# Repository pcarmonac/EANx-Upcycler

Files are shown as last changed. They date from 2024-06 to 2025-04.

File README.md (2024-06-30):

# EANx-Upcycler

Enhanced feature version on Platform IO of this project https://github.com/lbehrler/EANx-Analyzer-Arduino

# EANx-Analyzer-Arduino / ESP32 

> **Note:** If you have an issue with this project, please review your hardware docuemntation first.  If you are still having an issue or have a software specific issue, please open an issue [here](https://github.com/lbehrler/EANx-Upcycler/issues).

EANx Analysis with output to an OLED color display.
The code can be customized to match a wide variety of hardware.  The current version in the main branch is setup to use an ESP32-Pico-D4, a Seeeduino Xiao, or an Arduino Nano with an SPI interface OLED screen 240 x 240.

In its simplest form the EANx Analyzer reads an analog input from an ADS1115, converts it to voltage, grabs a running average of ADC values and and prints the result to the display and debug to Serial Monitor.

The EANx Analyzer project is meant to be a DIY O2 Analyzer.  

## Disclaimers

**Using or monitoring oxygen levels above atmospheric composition (20.9%) can be hazardous. While oxygen is not combustible or explosive, its presence accelerates and promotes combustion. High levels of oxygen will make most materials combustible including metals. Do not use oxygen levels above 20.9% in the presence of any flame or ignition source.**

**Use at your own risk.  Inaccurate gas analysis can lead to serious personal injury or death.**  

If you are using the device and software for critical purposes, please seek proper training and know the limits of devices of this type. By using this analyzer to analyze breathing gas, you assume all risks for the use of analyzed gas and the risk from any inferences made from the output of the device, both above and below the water.

## Acknowledgements
Some of this code is adapted from other EANx project scripts: 
  - https://github.com/ppppaoppp/DIY-Nitrox-Analyzer-04_12_2019.git
  - https://github.com/ejlabs/arduino-nitrox-analyzer.git

## Basic Operations 
Unit is rechargeable with any 5-20v USB-C negotiating charger (i.e. phone charger).  The unit has a battery meter in the upper right of the screen for the 16340 battery status, and in the upper left for the sensor unit.   If the sensor unit is yellow or red, please replace the O2 sensor, if the battery monitor is yellow or red please fully charge the unit before use. 

### Firmware and Package Upates
The recommended method for firmware updates or to reflash your device is to use the browser based updater here:  ([Firmware Update Page](https://lbehrler.github.io/EANxUpcycler.github.io/)).

Alternately updates can be made using Expressif's ESP Flash Download Tool or an online Serial Connection tool (https://serial.huhn.me/) to update the firmware on your device.  Do so with caution the firmware portion starts at 0x10000 memory position. 

## Project Files

The project folder contains several files and one folder:

+ `LICENSE` - The license file for this project
+ `readme.md` - This file.
+ `EANx_Analyzer_XXXXXXX.ino` - the basic application.
+ `pin_config.h` - Header file for various ESP32 / Arduino pinout settings. 
+ `OTA.h` - Simple OTA upate header (optional utility).
+ `bat_stat.h` - Simple Battery status script for ESP32 based boards.

## Configuration
Depending on your hardware configuration and components used you will have to set your pin definitions in the header files. 

If you are using a basic ST3%XX or ST13XX series display you can use [U8g2](https://github.com/olikraus/u8g2) or the Adafruit librarires. For more advance display features and better efficiency the [Bodmer TFT eSPI library](https://github.com/Bodmer/TFT_eSPI) can be configured allowing for greater options. If you are using the EANx Analyzer OLED TFT eSPI.ino then the TFT eSPI library is required. 

## Revision History
+ 11/29/2022 - initial release
+ 12/30/2022 - prototype release
+ 01/03/2023 - custom PCB prototype release
+ 07/20/2023 - custom PCB option ESP32 release

## Schematics 

*Seeeduino Xiao version with SPI OLED:*


## Prototype

The current prototype unit is built using:
+ LilyGo-T-OI-PLUS [ESP32 C3 with 16340 Battery holder](https://github.com/Xinyuan-LilyGO/LilyGo-T-OI-PLUS)
+ Generic ADS1115 
+ SPI Organic light-emitting diode (OLED) ST7789
+ O2 Sensor
+ 16340 Battery
+ Custom PCB fit to project case
+ Project case

*Prototype 4*

Custom PCB version

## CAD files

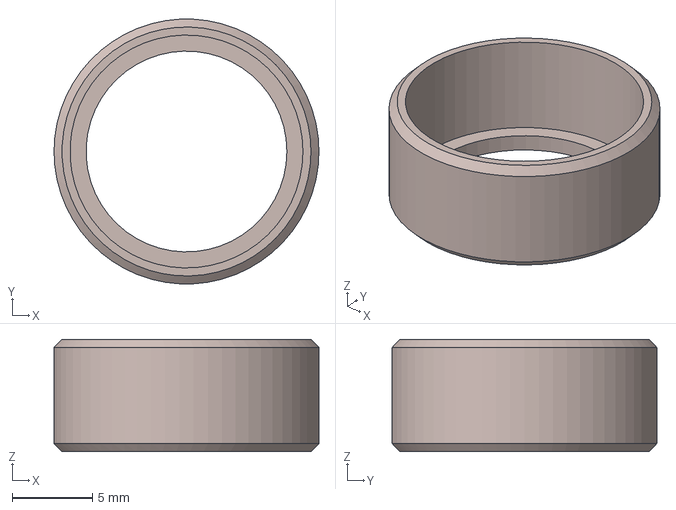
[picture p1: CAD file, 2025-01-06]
STL/EAN Switch Shroud V1.step
16.5 x 16.5 x 7.00 mm

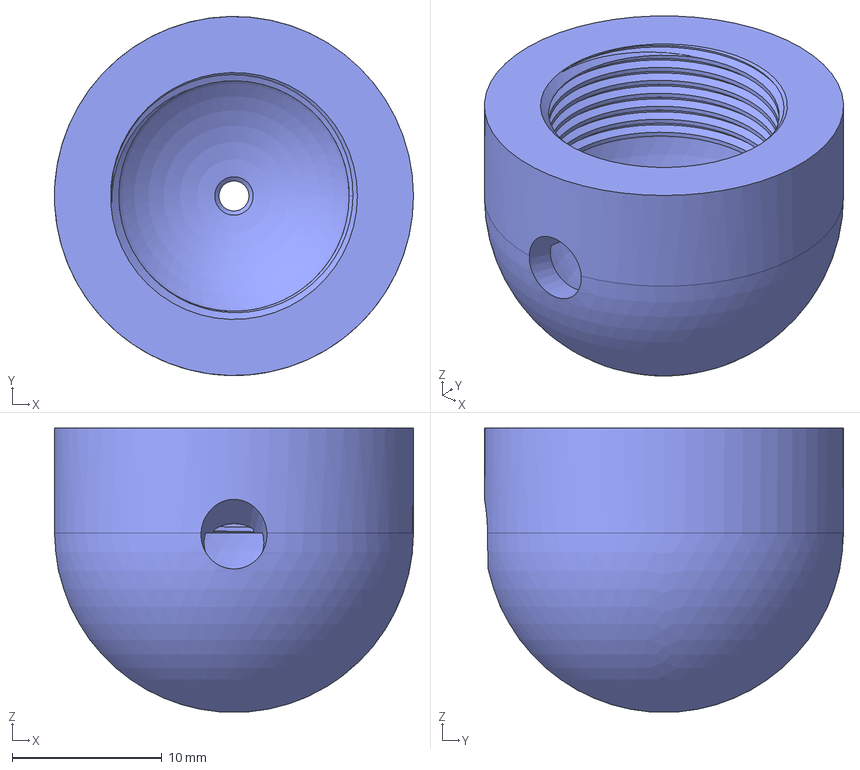
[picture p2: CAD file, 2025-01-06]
STL/EAN Cap V2.step
24.0 x 24.0 x 19.0 mm

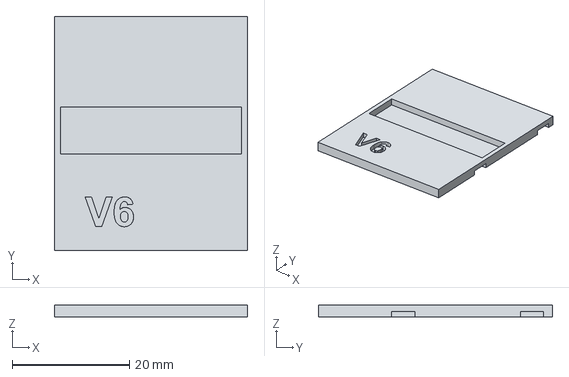
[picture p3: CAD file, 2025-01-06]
STL/EAN PCB Spacer V6.step
33.0 x 40.0 x 2.10 mm

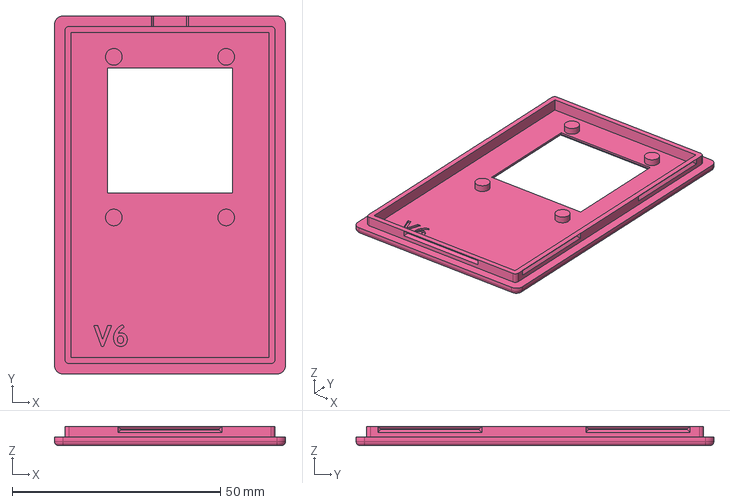
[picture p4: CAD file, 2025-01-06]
STL/EAN Lid V6.step
55.5 x 86.0 x 4.60 mm

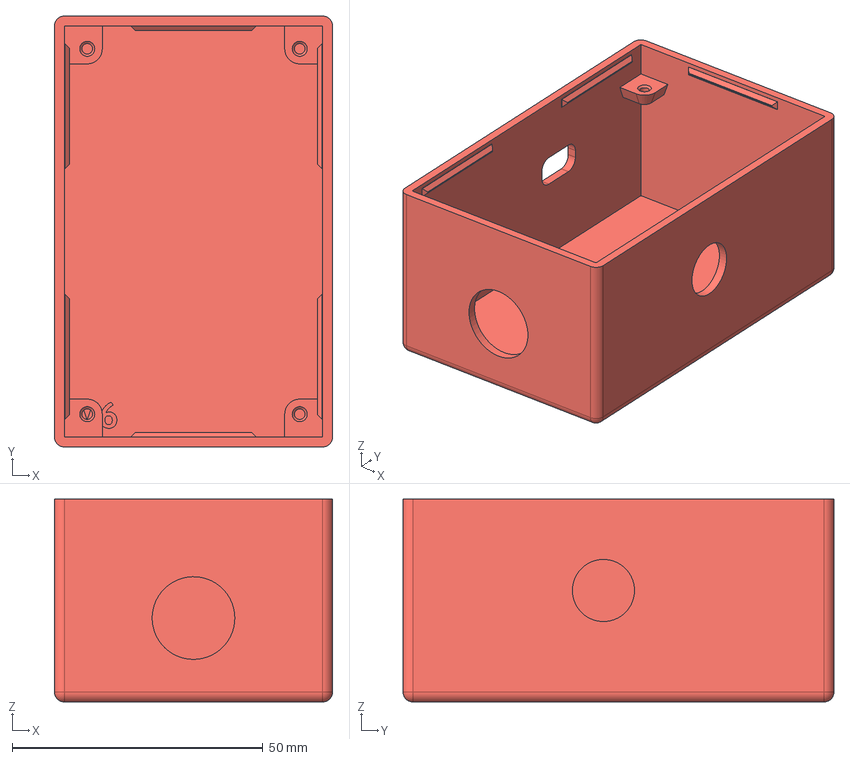
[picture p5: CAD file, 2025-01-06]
STL/EAN Box V6.step
55.5 x 86.0 x 40.5 mm

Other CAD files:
STL/EAN Box V6.stl
STL/EAN Lid V6.stl

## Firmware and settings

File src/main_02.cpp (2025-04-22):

/*****************************************************************************

  EANx Analysis with output to an OLED color display

  Reads an analog input from an ADC, converts it to mV, and creates a running average
  of ADC values and and prints the result to the display and debug to Serial Monitor.

  Based on prior EANx scripts:
  https://github.com/ppppaoppp/DIY-Nitrox-Analyzer-04_12_2019.gitf
  https://github.com/ejlabs/arduino-nitrox-analyzer.git

  Brian Ehrler 2022-2023
*****************************************************************************/

// Libraries
#include <Arduino.h>
// #include <Wire.h>
#include <RunningAverage.h>
#include <SPI.h>
#include <Adafruit_GFX.h> // Core graphics library
#include <TFT_eSPI.h>
#include <Adafruit_ADS1X15.h>
// #include <stdint.h>
#include "pin_config.h"
#include "version.h"
#include <EEPROM.h>

// Debugging
#define DEBUG 1

#if DEBUG == 1
#define debug(x) Serial.print(x)
#define debugln(x) Serial.println(x)
#else
#define debug(x)
#define debugln(x)
#endif

// Display Definitions
#define TFT_WIDTH 240  // OLED display width, in pixels
#define TFT_HEIGHT 240 // OLED display height, in pixels
#define ResFact 2      // 1 = 128x128   2 = 240x240 
#define ROUNDISP 0     // 1= yes 0= no

// User Interface Settings -----------------------------------------------------------------
#define GUI 0       // 1= on 0= off
#define nerds 1     // 1= on 0= off   GUI of 1 will override this setting
#define metric 0    // 1= on 0= off   Available since 1866 in the US
#define statinfo 1  // 2= bottom 1= top, 0= off [GUI requires off]
#define MOD 1       // 1= on 0= off
#define RODA 0      // 1= on 0= off


// Init tft and sprites
TFT_eSPI tft = TFT_eSPI();

TFT_eSprite gauge = TFT_eSprite(&tft);
TFT_eSprite background = TFT_eSprite(&tft);
TFT_eSprite needle = TFT_eSprite(&tft);
  
// Init ADS
Adafruit_ADS1115 ads; // Define ADC - 16-bit version

// Running Average definitions
#define RA_SIZE 20          // Define running average pool size
RunningAverage RA(RA_SIZE); // Initialize Running Average

// Global Variables
int LCDROT = 0; // 0 = default, 1 = CW 90
float tbFactor = 0;
float spFactor = 0;
float prevaveSensorValue = 0;
float aveSensorValue = 0;
float mVolts = 0;
float batVolts = 0;
int eepromAddr = 0;
float prevO2 = 0;
float currentO2 = 0;
float calFactor = 1;
float calErrChk = 1;
int mod14fsw = 0;
int mod14msw = 0;
int mod16fsw = 0;
int mod16msw = 0;
float modppo = 1.4;
float mod16ppo = 1.6;
float multiplier = 0;
int msgid = 0;

#if GUI == 1
// Define display colors
#define backColor TFT_BLACK
#define gaugeColor 0x055D
#define dataColor 0x0311
#define needleColor 0xF811
#define color1 TFT_WHITE
#define color2 0x8410
#define color3 TFT_ORANGE
#define color4 0x15B3
#define color5 0x00A3

#define DEG2RAD 0.0174532925

// Gauge variables
float o2Angle = 0;  // range 0-100
float modAngle = 0; // range 10-250

int centerX = 120; // centerX and sy
int centerY = -75;
int centerX2 = 120;
int centerY2 = 330;
int r = 180; // outer radius tickmarks ... offset r-5 for line end, r-15 for text

int uprAngle = 0;
int lwrAngle = 0;
int o2OffAgl = 90;
int modOffAgl = 270;

String o2[10] = {"0", "10", "20", "30", "40", "50", "60", "70", "80", "90"};
String mod[10] = {"0", "30", "60", "90", "120", "150", "180", "210", "240", "270"};
int o2Start[10];
int o2StartP[60];
int modStart[10];
int modStartP[60];

float x[360]; // pixel points O2 gauge
float y[360];
float px[360]; // line end points O2 gauge
float py[360];
float lx[360]; // text of O2 gauges
float ly[360];

float x2[360]; // outer points of MOD gauges
float y2[360];
float px2[360]; // ineer point of MOD gauges
float py2[360];
float lx2[360]; // text of MOD gauges
float ly2[360];

#endif

const int buttonPin = BUTTON_PIN; // push button

// Functions
float batStat();

/*void gotoSleep() 
{
  Serial.println("going to sleep in 3 sec....");   
  delay(3000); 
  esp_deep_sleep_enable_gpio_wakeup(1ULL << buttonPin,ESP_GPIO_WAKEUP_GPIO_HIGH);  
  digitalWrite(TFT_BL, LOW); // turns off backlight
  delay(120); // Delay for shutdown time before another command can be sent
  Serial.println("going to sleep now"); 
  delay(1000);
  tft.writecommand(0x10); // Sleep
  delay(5); // Delay for shutdown time before another command can be sent
  esp_deep_sleep_start();
  //esp_light_sleep_start();
}*/

void SenseFault()
{
  debugln("Low mV reading from Sensor");
  tft.fillScreen(TFT_YELLOW);
  tft.setTextColor(TFT_RED);
  tft.setTextSize(1 * ResFact);
  tft.drawCentreString("Error", TFT_WIDTH * 0.5, TFT_HEIGHT * 0.1, 4);
  tft.drawCentreString("Sensor mV", TFT_WIDTH * 0.5, TFT_HEIGHT * 0.4, 4);
  tft.drawCentreString("LOW", TFT_WIDTH * 0.5, TFT_HEIGHT * 0.7, 4);
  tft.setTextSize(1);
  tft.drawCentreString(String(mVolts), TFT_WIDTH * .5, TFT_HEIGHT * 0.8, 4);
  delay(30000);
}

void BattFault()
{
  debugln("Low V reading from Battery");
  tft.fillScreen(TFT_YELLOW);
  tft.setTextColor(TFT_RED);
  tft.setTextSize(1 * ResFact);
  tft.drawCentreString("Error", TFT_WIDTH * 0.5, TFT_HEIGHT * 0.1, 4);
  tft.drawCentreString("Battery", TFT_WIDTH * 0.5, TFT_HEIGHT * 0.4, 4);
  tft.drawCentreString("Low", TFT_WIDTH * 0.5, TFT_HEIGHT * 0.7, 4);
  tft.setTextSize(1);
  tft.drawCentreString(String(batVolts), TFT_WIDTH * .5, TFT_HEIGHT * 0.8, 4);
  delay(30000);
}

float initADC()
{
  // init ADC and Set gain

  // The ADC input range (or gain) can be changed via the following
  //                                                                ADS1015  ADS1115
  //                                                                -------  -------
  // ads.setGain(GAIN_TWOTHIRDS);  // 2/3x gain +/- 6.144V  1 bit = 3mV      0.1875mV (default)
  // ads.setGain(GAIN_ONE);        // 1x gain   +/- 4.096V  1 bit = 2mV      0.125mV
  ads.setGain(GAIN_TWO); // 2x gain   +/- 2.048V  1 bit = 1mV      0.0625mV
  // ads.setGain(GAIN_FOUR);       // 4x gain   +/- 1.024V  1 bit = 0.5mV    0.03125mV
  // ads.setGain(GAIN_EIGHT);      // 8x gain   +/- 0.512V  1 bit = 0.25mV   0.015625mV
  // ads.setGain(GAIN_SIXTEEN);    // 16x gain  +/- 0.256V  1 bit = 0.125mV  0.0078125mV

  /* Be sure to update this value based on the IC and the gain settings! */
  // float   multiplier = 3.0F;    /* ADS1015 @ +/- 6.144V gain (12-bit results) */
  float multiplier = 0.0625; /* ADS1115  @ +/- 6.144V gain (16-bit results) */

  // Check that the ADC is operational
  if (!ads.begin())
  {
    debugln("Failed to initialize ADC.");
    tft.fillScreen(TFT_YELLOW);
    tft.setTextColor(TFT_RED);
    tft.setTextSize(1 * ResFact);
    tft.drawCentreString("Error", TFT_WIDTH * 0.5, TFT_HEIGHT * 0.1, 4);
    tft.drawCentreString("ADC", TFT_WIDTH * 0.5, TFT_HEIGHT * 0.4, 4);
    tft.drawCentreString("Fail", TFT_WIDTH * 0.5, TFT_HEIGHT * 0.7, 4);
    delay(30000);
    while (1);
  }
  return (multiplier);
}

void o2calibration()
{
  int cal = 1;
  do
  {
    // display "Calibrating"
    tft.fillScreen(TFT_BLACK);
    tft.setTextColor(TFT_WHITE);
    tft.setTextSize(1 * ResFact);
    tft.drawCentreString("+++++++++++++", TFT_WIDTH * 0.5, TFT_HEIGHT * 0.1, 2);
    tft.drawCentreString("Calibrating", TFT_WIDTH * 0.5, TFT_HEIGHT * 0.3, 2);
    tft.drawCentreString("O2 Sensor", TFT_WIDTH * 0.5, TFT_HEIGHT * 0.6, 2);
    tft.drawCentreString("+++++++++++++", TFT_WIDTH * 0.5, TFT_HEIGHT * 0.8, 2);
    debugln("Calibration Screen Text");

    // get running average value from ADC input Pin
    RA.clear(); 
    for (int x = 0; x <= (RA_SIZE * 3); x++)
    {
      int sensorValue = 0;
      sensorValue = abs(ads.readADC_Differential_0_1());
      RA.addValue(sensorValue);
      delay(12); // was 8
    }
    debug("Average calibration read ");
    debugln(RA.getAverage()); // average cal factor serial print for debugging
    calFactor = RA.getAverage();
    delay(1000); // Slow the loop for checksum

    // Checksum on calibrate ... is the sensor still reseting from earlier read
    RA.clear();
    for (int x = 0; x <= (RA_SIZE * 3); x++)
    {
      int sensorValue = 0;
      sensorValue = abs(ads.readADC_Differential_0_1());
      RA.addValue(sensorValue);
      delay(36); // was 24
    }

    tft.fillScreen(TFT_BLACK);

    calErrChk = RA.getAverage();
    debug("calibration raw values Calfactor=");
    debug(calFactor); // average cal factor
    debug(" CalErrChk=");
    debugln(calErrChk); // average cal err factor serial print for debugging

    debugln(abs((calFactor / calErrChk) - 1) * 100);

    // checking against a 0.5% error
    if (abs((calFactor / calErrChk) - 1) * 100 > 0.5)
    {
      debugln("Calibration Checksum out of spec");
      tft.fillScreen(TFT_ORANGE);
      tft.setTextColor(TFT_BLACK);
      tft.setTextSize(1 * ResFact);
      tft.drawCentreString("+++++++++++++", TFT_WIDTH * 0.5, TFT_HEIGHT * 0.1, 2);
      tft.drawCentreString("Refining", TFT_WIDTH * 0.5, TFT_HEIGHT * 0.25, 2);
      tft.drawCentreString("Calibration", TFT_WIDTH * 0.5, TFT_HEIGHT * 0.45, 2);
      tft.drawCentreString("Standby", TFT_WIDTH * 0.5, TFT_HEIGHT * 0.65, 2);
      tft.drawCentreString("+++++++++++++", TFT_WIDTH * 0.5, TFT_HEIGHT * 0.80, 2);
      tft.drawCentreString(String(abs((calFactor / calErrChk) - 1) * 100), TFT_WIDTH * 0.5, TFT_HEIGHT * 0.80, 1);
      delay(2000);
      cal = 1;
    }
    else
    {
      cal = 0;
    }
  } while (cal);

  calFactor = (1 / RA.getAverage() * 20.900); // Auto Calibrate to 20.9%
}

void BatGauge(int locX, int locY, float batV)
{

#if GUI == 1
  // Add to gauge sprite
  gauge.drawRect(locX, locY, 25, 12, TFT_WHITE);
  gauge.drawRect((locX + 25), (locY + 4), 3, 4, TFT_WHITE);
  gauge.fillRect((locX + 1), (locY + 1), 23, 10, TFT_BLACK);

  // Fill with the color that matches the charge state
  if (batV >= 3.4 and batV < 3.6)
  {
    gauge.fillRect((locX + 1), (locY + 1), 15, 10, TFT_YELLOW);
  }
  if (batV < 3.4)
  {
    gauge.fillRect((locX + 1), (locY + 1), 10, 10, TFT_RED);
  }
  if (batV >= 3.6)
  {
    gauge.fillRect((locX + 1), (locY + 1), 23, 10, TFT_GREEN);
  }
#else
  // Draw the outline and clear the box
  tft.drawRect(locX, locY, 25, 12, TFT_WHITE);
  tft.drawRect((locX + 25), (locY + 4), 3, 4, TFT_WHITE);
  tft.fillRect((locX + 1), (locY + 1), 23, 10, TFT_BLACK);

  // Fill with the color that matches the charge state
  if (batV > 3.4 and batV < 3.6)
  {
    tft.fillRect((locX + 1), (locY + 1), 15, 10, TFT_YELLOW);
  }
  if (batV < 3.4)
  {
    tft.fillRect((locX + 1), (locY + 1), 10, 10, TFT_RED);
  }
  if (batV > 3.6)
  {
    tft.fillRect((locX + 1), (locY + 1), 23, 10, TFT_GREEN);
  }
#endif
  if (batV < 3.2) { BattFault(); }

}

void SenseGauge(int locX, int locY, float senV)
{

#if GUI == 1
  // Draw the outline and clear the box
  gauge.drawRect(locX, locY, 25, 12, TFT_WHITE);
  gauge.drawRect((locX + 5), (locY - 3), 4, 3, TFT_WHITE);
  gauge.drawRect((locX + 16), (locY - 3), 4, 3, TFT_WHITE);
  gauge.fillRect((locX + 1), (locY + 1), 23, 10, TFT_BLACK);

  // Fill with the color that matches the charge state
  if (senV >= 9.0)
  {
    gauge.fillRect((locX + 1), (locY + 1), 23, 10, TFT_BLUE);
  }
  if (senV >= 8 and senV < 9.0 )
  {
    gauge.fillRect((locX + 1), (locY + 1), 23, 10, TFT_GREEN);
  }
  if (senV > 7.5 and senV < 8.0)
  {
    gauge.fillRect((locX + 1), (locY + 1), 23, 10, TFT_YELLOW);
  }
  if (senV <= 7.5)
  {
    gauge.fillRect((locX + 1), (locY + 1), 23, 10, TFT_RED);
  }

#else
  // Draw the outline and clear the box
  tft.drawRect(locX, locY, 25, 12, TFT_WHITE);
  tft.drawRect((locX + 5), (locY - 3), 4, 3, TFT_WHITE);
  tft.drawRect((locX + 16), (locY - 3), 4, 3, TFT_WHITE);
  tft.fillRect((locX + 1), (locY + 1), 23, 10, TFT_BLACK);

  // Fill with the color that matches the charge state
  if (senV > 7.5 and senV < 8.0)
  {
    tft.fillRect((locX + 1), (locY + 1), 23, 10, TFT_YELLOW);
  }
  if (senV >= 8 and senV < 9.0 )
  {
    tft.fillRect((locX + 1), (locY + 1), 23, 10, TFT_GREEN);
  }
  if (senV <= 7.5)
  {
    tft.fillRect((locX + 1), (locY + 1), 23, 10, TFT_RED);
  }
  if (senV >= 9.0)
  {
    tft.fillRect((locX + 1), (locY + 1), 23, 10, TFT_BLUE);
  }
#endif

if (senV < 7.1) { SenseFault(); }

}

void testfillcircles(uint8_t radius, uint16_t color)
{
  for (int16_t x = radius; x < tft.width(); x += radius * 2)
  {
    for (int16_t y = radius; y < tft.height(); y += radius * 2)
    {
      tft.fillCircle(x, y, radius, color);
    }
  }
}

void testdrawcircles(uint8_t radius, uint16_t color)
{
  for (int16_t x = 0; x < tft.width() + radius; x += radius * 2)
  {
    for (int16_t y = 0; y < tft.height() + radius; y += radius * 2)
    {
      tft.drawCircle(x, y, radius, color);
    }
  }
}

void safetyrule()
{
  tft.fillScreen(TFT_BLACK);
  tft.setTextColor(TFT_YELLOW);
  tft.setTextSize(1 * ResFact);
  randomSeed(millis());
  int randNumber = random(5);
  if (randNumber == 0)
  {
    tft.drawCentreString("Seek proper", TFT_WIDTH * 0.5, TFT_HEIGHT * 0.1, 2);
    tft.drawCentreString("training", TFT_WIDTH * 0.5, TFT_HEIGHT * 0.25, 2);
  }
  else if (randNumber == 1)
  {
    tft.drawCentreString("Maintain a", TFT_WIDTH * 0.5, TFT_HEIGHT * 0.1, 2);
    tft.drawCentreString("continious", TFT_WIDTH * 0.5, TFT_HEIGHT * 0.25, 2);
    tft.drawCentreString("guideline to", TFT_WIDTH * 0.5, TFT_HEIGHT * 0.4, 2);
    tft.drawCentreString("the surface", TFT_WIDTH * 0.5, TFT_HEIGHT * 0.55, 2);
  }
  else if (randNumber == 2)
  {
    tft.drawCentreString("Stay within", TFT_WIDTH * 0.5, TFT_HEIGHT * 0.1, 2);
    tft.drawCentreString("your depth", TFT_WIDTH * 0.5, TFT_HEIGHT * 0.25, 2);
    tft.drawCentreString("limitations", TFT_WIDTH * 0.5, TFT_HEIGHT * 0.4, 2);
  }
  else if (randNumber == 3)
  {
    tft.drawCentreString("Proper gas", TFT_WIDTH * 0.5, TFT_HEIGHT * 0.1, 2);
    tft.drawCentreString("management", TFT_WIDTH * 0.5, TFT_HEIGHT * 0.25, 2);
  }
  else
  {
    tft.drawCentreString("Use appropriate", TFT_WIDTH * 0.5, TFT_HEIGHT * 0.1, 2);
    tft.drawCentreString("properly maintaned", TFT_WIDTH * 0.5, TFT_HEIGHT * 0.25, 2);
    tft.drawCentreString("equipment", TFT_WIDTH * 0.5, TFT_HEIGHT * 0.4, 2);
  }
  delay(2000);
  tft.fillScreen(TFT_BLACK);
}

void displayUtilData()
{

  BatGauge((TFT_WIDTH * 0.8), (TFT_HEIGHT * (tbFactor + 0.02)), (batVolts));
  SenseGauge((TFT_WIDTH * 0.1), (TFT_HEIGHT * (tbFactor + 0.02)), (mVolts));

  // Stats for nerds text
  #if (nerds == 1 and GUI == 0)

    tft.setTextSize(1);
    if (mVolts > 7.5 and mVolts <= 9.0) { tft.setTextColor(TFT_YELLOW, TFT_BLACK); }
    if (mVolts <= 7.5) { tft.setTextColor(TFT_RED, TFT_BLACK); }
    if (mVolts > 9.0) { tft.setTextColor(TFT_SKYBLUE, TFT_BLACK); }
    if (mVolts < 7.1) { SenseFault(); }
    String mv = String(mVolts, 1);

    tft.drawCentreString(String(mv + " mV "), TFT_WIDTH * 0.18, TFT_HEIGHT * 0.1, 2);

    if (batVolts > 3.4 and batVolts < 3.6) { tft.setTextColor(TFT_YELLOW, TFT_BLACK); }
    if (batVolts < 3.4) { tft.setTextColor(TFT_RED, TFT_BLACK); }
    if (batVolts > 3.6) { tft.setTextColor(TFT_GREEN, TFT_BLACK); }

    String bv = String(batVolts, 1);
    if (batVolts < 3.2) { BattFault(); }

    tft.drawCentreString(String(bv + " V  "), TFT_WIDTH * 0.88, TFT_HEIGHT * 0.1, 2);

    //tft.drawString(String(millis() / 1000), TFT_WIDTH * 0.05, TFT_HEIGHT * 0, 2);
    tft.setTextSize(1);
    tft.setTextColor(TFT_LIGHTGREY, TFT_BLACK);
    tft.drawCentreString(String(VERSION), TFT_WIDTH * 0.5, TFT_HEIGHT * 0.93, 2);
  #endif
}

#if GUI == 0
void textBaseLayout()
{
  // Draw Layout -- Adjust this layouts to suit you LCD

  tft.setTextColor(TFT_MAGENTA, TFT_BLACK);
  tft.setTextSize(1 * ResFact);
  tft.drawCentreString("O %", TFT_WIDTH * 0.5, TFT_HEIGHT * 0, 4);
  tft.setTextSize(1);
  tft.drawCentreString("2", TFT_WIDTH * 0.5, TFT_HEIGHT * 0.1, 4);
  tft.setTextSize(1 * ResFact);
  tft.setTextColor(TFT_ORANGE, TFT_BLACK);
  if (MOD == 1)
  {
    tft.drawCentreString("@1.4  MOD  @1.6", TFT_WIDTH * 0.5, TFT_HEIGHT * 0.62, 2);
  }
  
  debugln("Base layout");
}

void displayTextData()
{
  // Generate Text layout
  if (prevO2 != currentO2)
  {
    if (currentO2 > 19.5 and currentO2 < 22)
    {
      tft.setTextColor(TFT_CYAN, TFT_BLACK);
    }
    if (currentO2 <= 19.5)
    {
      tft.setTextColor(TFT_YELLOW, TFT_BLACK);
    }
    if (currentO2 <= 17)
    {
      tft.setTextColor(TFT_RED, TFT_BLACK);
    }
    if (currentO2 >= 22)
    {
      tft.setTextColor(TFT_GREEN, TFT_BLACK);
    }

    // Draw Text Layout -- Adjust these layouts to suit you LCD
    tft.setTextSize(1 * ResFact);
    String o2 = String(currentO2, 1);
    float h = 0.22;
    if (MOD == 0)
    {
      h = 0.35;
    }

    tft.drawCentreString(o2, TFT_WIDTH * 0.5, TFT_HEIGHT * h, 7);
    debugln("Write O2 string");
  
    tft.setTextSize(1 * ResFact);
    if (MOD == 1)
    {
      if (metric == 1)
      {
        String mod14m = String(mod14msw);
        tft.setTextColor(TFT_GREENYELLOW, TFT_BLACK);
        tft.drawString(String(mod14m + "-m  "), TFT_WIDTH * 0.05, TFT_HEIGHT * 0.75, 2);
        tft.setTextColor(TFT_GOLD, TFT_BLACK);
        String mod16m = String(mod16msw);
        tft.drawString(String(mod16m + "-m  "), TFT_WIDTH * 0.7, TFT_HEIGHT * 0.75, 2);
      }
      else
      {
        tft.setTextColor(TFT_GREENYELLOW, TFT_BLACK);
        String mod14f = String(mod14fsw);
        tft.drawString(String(mod14f + "-FT  "), TFT_WIDTH * 0, TFT_HEIGHT * 0.75, 2);
        tft.setTextColor(TFT_GOLD, TFT_BLACK);
        String mod16f = String(mod16fsw);
        tft.drawString(String(mod16f + "-FT  "), TFT_WIDTH * 0.6, TFT_HEIGHT * 0.75, 2);
      }
    }
  }
}
#endif

#if GUI == 1
void gaugeBaseLayout()
{
  // Draw Layout -- Adjust this layouts to suit you LCD
  gauge.createSprite(TFT_WIDTH, 240);
  gauge.setSwapBytes(true);
  gauge.setTextDatum(4);
  gauge.setTextColor(TFT_WHITE, backColor);
  needle.createSprite(TFT_WIDTH, 240);
  needle.setSwapBytes(true);
  background.createSprite(TFT_WIDTH, 240);
  background.setSwapBytes(true);
  background.fillSprite(TFT_BLACK);

  int b = 0;
  int b2 = 0;
  int c = 0;
  int c2 = 0;

  // Set up polar coordinates for gauge
  for (int i = 0; i < 360; i++)
  {
    x[i] = ((r)*cos(DEG2RAD * i)) + centerX; // Shading
    y[i] = ((r)*sin(DEG2RAD * i)) + centerY;
    px[i] = ((r - 14) * cos(DEG2RAD * i)) + centerX; // pick marks
    py[i] = ((r - 14) * sin(DEG2RAD * i)) + centerY;
    lx[i] = ((r - 24) * cos(DEG2RAD * i)) + centerX; // line ends
    ly[i] = ((r - 24) * sin(DEG2RAD * i)) + centerY;

    if (i % 36 == 0)
    {
      o2Start[b] = i;
      b++;
    }

    if (i % 6 == 0)
    {
      o2StartP[b2] = i;
      b2++;
    }

    x2[i] = ((r)*cos(DEG2RAD * i)) + centerX2; // Shading
    y2[i] = ((r)*sin(DEG2RAD * i)) + centerY2;
    px2[i] = ((r - 14) * cos(DEG2RAD * i)) + centerX2; // pick marks
    py2[i] = ((r - 14) * sin(DEG2RAD * i)) + centerY2;
    lx2[i] = ((r - 24) * cos(DEG2RAD * i)) + centerX2; // line ends
    ly2[i] = ((r - 24) * sin(DEG2RAD * i)) + centerY2;

    if (i % 36 == 0)
    {
      modStart[c] = i;
      c++;
    }

    if (i % 6 == 0)
    {
      modStartP[c2] = i;
      c2++;
    }
  }

  debugln("Gauges Create");
}
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
void loop()
{

  multiplier = initADC();
  /* debugln("Button Check");

  int bstate = digitalRead(buttonPin);
  //debugln(bstate);
  if (bstate == LOW) // must be LOW for TTGO OI
  {
    //gotoSleep();

    if (LCDROT == 0)
    {
      LCDROT = 2;
    }
    // Configuración inicial
    EEPROM.begin(4);
    metric = EEPROM.read(eepromAddr);
    
    // Lógica de cambio de unidades
    else if (metric == 0) {
    metric = 1;
    EEPROM.write(eepromAddr, metric);
    EEPROM.commit();
    prevO2 = -1;  // Forzar actualización
    tft.fillScreen(TFT_BLACK);
    }
    else
    {
      metric = 0;
      EEPROM.write(eepromAddr, metric);
      EEPROM.commit();
      prevO2 = -1;
      tft.fillScreen(TFT_BLACK);
    }
      //digitalWrite(TFT_BL, LOW); // turns off backlight

    }
    else
    {
      LCDROT = 0;
      //digitalWrite(TFT_BL, HIGH); // turns off backlight
    }
    tft.setRotation(LCDROT);
    tft.fillScreen(TFT_BLACK);
  }

*/
  // get running average value from ADC input Pin
  RA.clear();
  for (int x = 0; x <= RA_SIZE; x++)
  {
    int sensorValue = 0;
    sensorValue = abs(ads.readADC_Differential_0_1());
    RA.addValue(sensorValue);
    delay(8); // was 16
    // debugln(sensorValue);    //mV serial print for debugging
  }

  delay(100); // slowing down loop a bit

  // Record old and new ADC values
  prevaveSensorValue = aveSensorValue;
  prevO2 = currentO2;
  aveSensorValue = RA.getAverage();

  currentO2 = (aveSensorValue * calFactor); // Units: pct

  // currentO2 = currentO2 + 5; // Test Values

  if (currentO2 > 99.9)
    currentO2 = 99.9;

  mVolts = (aveSensorValue * multiplier); // Units: mV

#ifdef ESP32
    batVolts = (batStat() / 1000) * BAT_ADJ; // Battery Check ESP based boards
#endif

  mod14fsw = floor(33 * ((modppo / (currentO2 / 100)) - 1));
  mod14msw = floor(10 * ((modppo / (currentO2 / 100)) - 1));
  mod16fsw = floor(33 * ((mod16ppo / (currentO2 / 100)) - 1));
  mod16msw = floor(10 * ((mod16ppo / (currentO2 / 100)) - 1));

  // DEBUG print out the value you read:
  msgid++;
  debug("Msg_ID:");
  debug(msgid);
  debug("\t");
  debug("ADC:");
  debug(aveSensorValue);
  debug("\t");
  debug("Sensor_mV:");
  debug(mVolts);
  debug("\t");
  debug("Batt_V:");
  debug(batVolts);
  debug("\t");
  debug("O2:");
  debug(currentO2);
  debug("\t");
  debug("MOD 1.4:");
  debug(mod14fsw);
  debug("\t");
  debug("MOD 1.6:");
  debugln(mod16fsw);

#if statinfo != 0
  textBaseLayout();
  displayUtilData();
#endif

#if GUI == 1
  displayGaugeData(); // Graphic Layout
#else
  displayTextData(); // Text Layout
#endif
}

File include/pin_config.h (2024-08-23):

// Chip Specific settings to interface battery status and LCD

#if defined(SEEED_XIAO_M0)  // Seeed XIAO
  #define SDA           4     
  #define SCL           5
  #define TFT_CS        2
  #define TFT_RST       -1     // Or set to -1 and connect to Arduino RESET pin
  #define TFT_DC        3
  #define TFT_MOSI      10    // Data out
  #define TFT_SCLK      8     // Clock out
  #define BUTTON_PIN    1
  #define VAL_MCU       "Seeed Xiao M0"

#elif defined(ARDUINO_XIAO_ESP32C3)  // Seeed XIAO ESP32 C3
  #define SDA           6     
  #define SCL           7
  #define TFT_CS        9  
  #define TFT_DC        3 
  #define TFT_MOSI      10    // Data out
  #define TFT_SCLK      8     // Clock out  
  #define TFT_RST       4     // Or set to -1 and connect to Arduino RESET pin 
  #define TFT_BL        5
  #define BUTTON_PIN    2
  #define VAL_MCU       "Seeed Xiao ESP32 C3"
  #include "bat_stat.h"
  #define BAT_ADJ       3.5

#elif defined(XXX_ARDUINO_ARCH_ESP32) // Denky
  #define SDA         21     
  #define SCL         22
  #define TFT_MOSI    13 // In some display driver board, it might be written as "SDA" and so on.
  #define TFT_SCLK    14
  #define TFT_CS      15  // Chip select control pin
  #define TFT_DC      2  // Data Command control pin
  #define TFT_RST     -1  // Reset pin (could connect to Arduino RESET pin)
  #define TFT_BL      27  // LED back-light
  #define TOUCH_CS    33     // Chip select pin (T_CS) of touch screen
  #define BUTTON_PIN  -1
  #define VAL_MCU       "ESP32 Elecrow"
  #include "bat_stat.h"
  #define BAT_ADJ       15.0

#elif defined(ARDUINO_TINYS3)
  #define TFT_SDA       8    
  #define TFT_SCL       9
  #define TFT_MISO      37
  #define TFT_MOSI      35    // Data out
  #define TFT_SCLK      36    // Clock out  #define 
  #define TFT_RST       -1    // Or set to -1 and connect to Arduino RESET pin                                            
  #define TFT_DC        3
  #define TFT_CS        34
  #define BUTTON_PIN    4
  #define VAL_MCU       "UM Tiny S3 ESP32"
  #include "bat_stat.h"
  #define BAT_ADJ       1.9
    
#elif defined(ARDUINO_ESP32C3_DEV)
  #define SDA       4   
  #define SCL       5
  #define TFT_MOSI      7
  #define TFT_SCLK      6
  #define TFT_CS        10  // Chip select control pin
  #define TFT_DC        2  // Data Command control pin
  #define TFT_RST      -1  // Reset pin (could connect to RST pin)
  #define TFT_BL        3
  #define BUTTON_PIN    9
  #define VAL_MCU       "ESP32-C3-2424S0122"
  #include "bat_stat.h"
  #define BAT_ADJ       1.9

#elif defined(ARDUINO_TTGO_T_OI_PLUS_DEV)  //Lilygo OI
  #define SDA           19    
  #define SCL           18

  // Traditional Pin Setup
  #define TFT_MOSI      6    // Data out
  #define TFT_SCLK      4    // Clock out  #define 
  #define TFT_DC        10
  #define TFT_CS        5    //Unused MISO pin

  /*// Hybrid Straight Line PCB Setup
  #define TFT_CS        4
  #define TFT_DC        5
  #define TFT_MOSI      6    // Data out
  #define TFT_SCLK      10   // Clock out  */
  
  #define TFT_RST       -1   // Or set to -1 and connect to Arduino RESET pin
  #define BUTTON_PIN    9
  #define VAL_MCU       "TTGO T-OI PLUS RISC-V ESP32-C3"
  #include "bat_stat.h"
  #define BAT_ADJ       1.0
  
#else
  // For the breakout board, you can use any 2 or 3 pins.
  // These pins will also work for the 1.8" TFT shield.
  //#define TFT_RST       -1    // Or set to -1 and connect to Arduino RESET pin                                            
  //#define TFT_DC        4
  //#define TFT_CS        10
  #define VAL_MCU       "Unknown"
  #define SDA         21     
  #define SCL         22
  #define TFT_MOSI    13 // In some display driver board, it might be written as "SDA" and so on.
  #define TFT_SCLK    14
  #define TFT_CS      15  // Chip select control pin
  #define TFT_DC      2  // Data Command control pin
  #define TFT_RST     -1  // Reset pin (could connect to Arduino RESET pin)
  #define TFT_BL      27  // LED back-light
  #define TOUCH_CS    33     // Chip select pin (T_CS) of touch screen
  #define BUTTON_PIN  4
  #include "bat_stat.h"
  #define BAT_ADJ       4.0

#endif

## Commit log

2023-01-17 Added ABS to eliminate polarity of O2 sensors
2023-01-19 Pin changes
2023-01-29 Added battery graphic
2023-02-25 Added prototype to onboard version info
2023-02-25 low mV error message
    [main.cpp]
2023-04-04 Added Calibration Error Checking
    [main.cpp]
2023-04-04 Added Error Check for Calibration of Sensor
    [main.cpp]
2023-04-07 ESP32 C3 Compatability
2023-04-13 Added Flip Display Function
    [main.cpp]
2023-10-02 Low Sensor mV fix
    [main.cpp, pin_config.h]
2025-01-06 Updated Error Checking for O2 readings
    [main.cpp]
2025-01-06 Adding STL for 3d Printed Case
    [EAN Box V6.step, EAN Cap V2.step, EAN Lid V6.step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]
2025-04-22 Creacion main_02
    Se crea main_02 para optimizar codigo y agregar funcion de metrico e imperial
